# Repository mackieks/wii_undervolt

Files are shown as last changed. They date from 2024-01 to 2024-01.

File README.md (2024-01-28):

Adjustable regulator board for Wii undervolting testing and current measurement. Solderpad Hardware License v2.1 
 


- 3.5 - 5.5V input
- x4 MUN3CAD03-SE 0.6-3.3V 3A buck regulators
- Trimpots for output voltage adjustment (feedback resistors pre-tuned for Wii undervolting)
- 4-terminal current sense resistors for input and outputs
- [Mouser project with BOM
](https://www.mouser.com/ProjectManager/ProjectDetail.aspx?AccessID=8f9d8d9514)
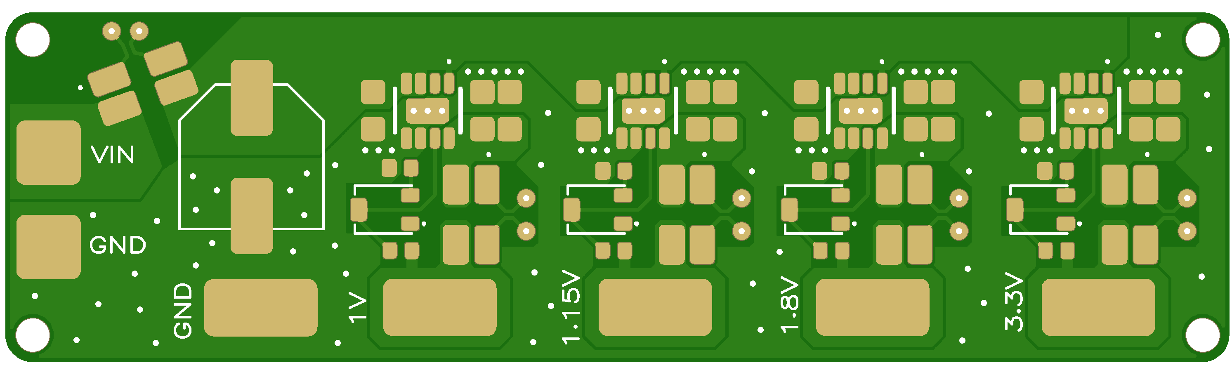
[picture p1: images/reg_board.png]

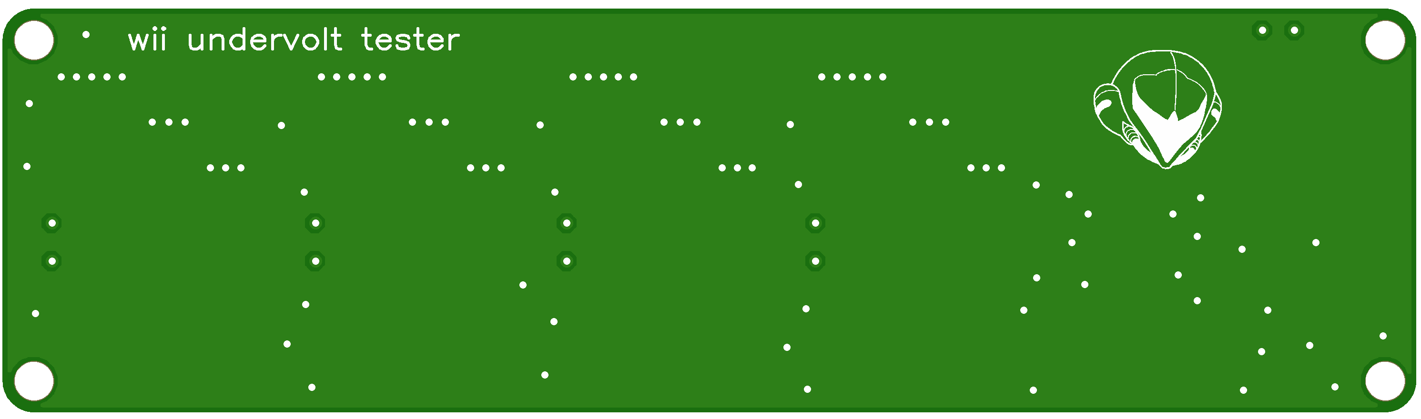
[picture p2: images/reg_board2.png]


Vin and each regulator output have dedicated 100-milliohm 4-terminal sense resistors. When powering a load from the reg board, you can measure across the resistors by poking your multimeter probes into the plated test pads. Multiply the voltage by 10 to get the load current in amps.

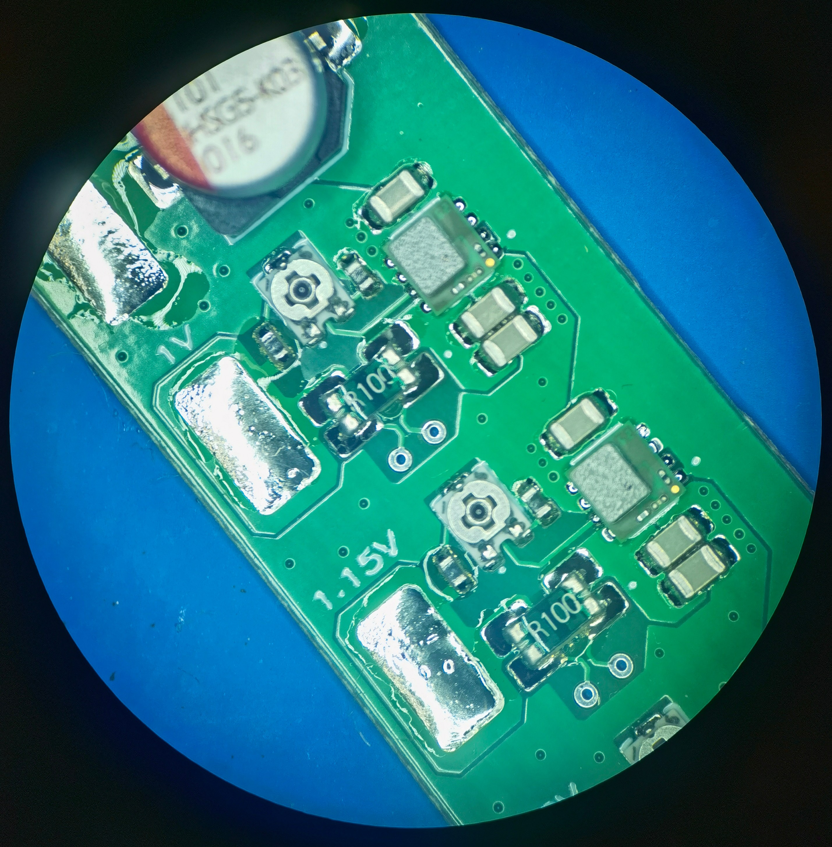
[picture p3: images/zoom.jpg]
 

Each regulator has a trimpot for adjusting the voltage. Turn it clockwise to increase Vout, and counterclockwise to decrease Vout. You can turn the pots with tweezers or a tiny, blunt Phillips screwdriver. The Vout ranges are bounded by resistors so that the entire pot range is usable (and to avoid pumping 5v into any of the rails.)

**Note:** the trimpots are fragile mechanical devices. If you turn them too far in one direction, they'll 'wrap around' to the other side. When overturned like this, there's a small region that won't produce a reasonable resistance, causing Vout to collapse. Just keep turning and Vout will jump back to the intended range.



## Schematic
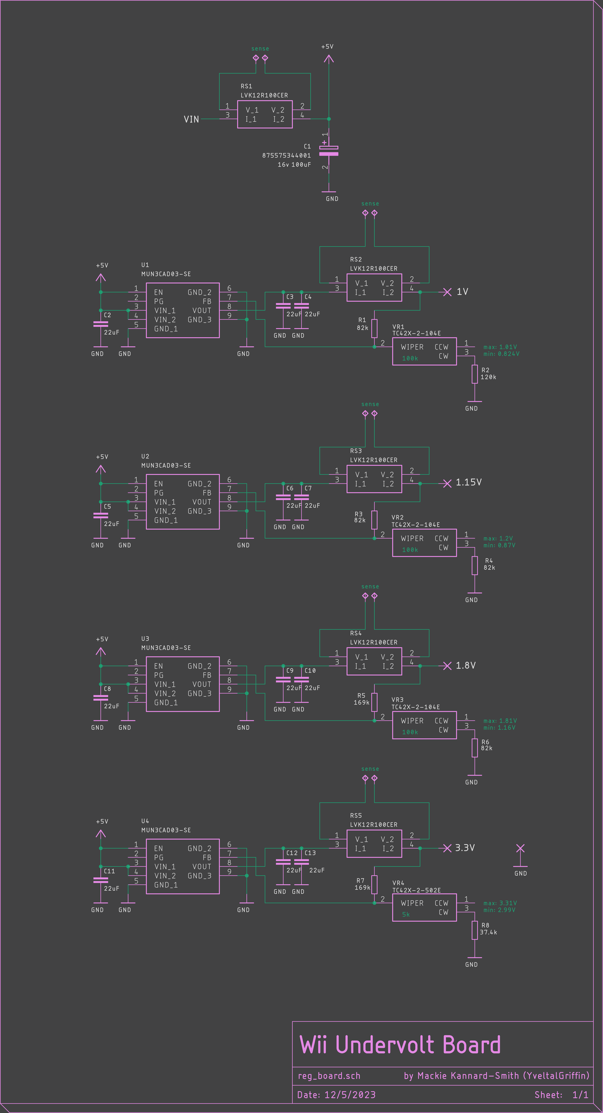
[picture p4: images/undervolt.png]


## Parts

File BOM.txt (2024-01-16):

Partlist

Exported from reg_board.sch at 1/16/2024 12:08 PM

EAGLE Version 9.6.2 Copyright (c) 1988-2020 Autodesk, Inc.

Assembly variant: 

Part     Value          Device       Package       Library        Sheet

C1       875575344001   875575344001 CAPAE660X610N SamacSys_Parts 1
C2       22uF           C-USC0603    C0603         resistor       1
C3       22uF           C-USC0603    C0603         resistor       1
C4       22uF           C-USC0603    C0603         resistor       1
C5       22uF           C-USC0603    C0603         resistor       1
C6       22uF           C-USC0603    C0603         resistor       1
C7       22uF           C-USC0603    C0603         resistor       1
C8       22uF           C-USC0603    C0603         resistor       1
C9       22uF           C-USC0603    C0603         resistor       1
C10      22uF           C-USC0603    C0603         resistor       1
C11      22uF           C-USC0603    C0603         resistor       1
C12      22uF           C-USC0603    C0603         resistor       1
C13      22uF           C-USC0603    C0603         resistor       1
R1       82k            R-US_R0402   R0402         resistor       1
R2       120k           R-US_R0402   R0402         resistor       1
R3       82k            R-US_R0402   R0402         resistor       1
R4       82k            R-US_R0402   R0402         resistor       1
R5       169k           R-US_R0402   R0402         resistor       1
R6       82k            R-US_R0402   R0402         resistor       1
R7       169k           R-US_R0402   R0402         resistor       1
R8       37.4k          R-US_R0402   R0402         resistor       1
RS1      LVK12R100CER   LVK12R100CER LVK12R100CER  SamacSys_Parts 1
RS2      LVK12R100CER   LVK12R100CER LVK12R100CER  SamacSys_Parts 1
RS3      LVK12R100CER   LVK12R100CER LVK12R100CER  SamacSys_Parts 1
RS4      LVK12R100CER   LVK12R100CER LVK12R100CER  SamacSys_Parts 1
RS5      LVK12R100CER   LVK12R100CER LVK12R100CER  SamacSys_Parts 1
U1       MUN3CAD03-SE   MUN3CAD03-SE MUN3CAD03SE   SamacSys_Parts 1
U2       MUN3CAD03-SE   MUN3CAD03-SE MUN3CAD03SE   SamacSys_Parts 1
U3       MUN3CAD03-SE   MUN3CAD03-SE MUN3CAD03SE   SamacSys_Parts 1
U4       MUN3CAD03-SE   MUN3CAD03-SE MUN3CAD03SE   SamacSys_Parts 1
VR1      TC42X-2-104E   TC42X-2-104E TC42X2103E    SamacSys_Parts 1
VR2      TC42X-2-104E   TC42X-2-104E TC42X2103E    SamacSys_Parts 1
VR3      TC42X-2-104E   TC42X-2-104E TC42X2103E    SamacSys_Parts 1
VR4      TC42X-2-502E   TC42X-2-104E TC42X2103E    SamacSys_Parts 1

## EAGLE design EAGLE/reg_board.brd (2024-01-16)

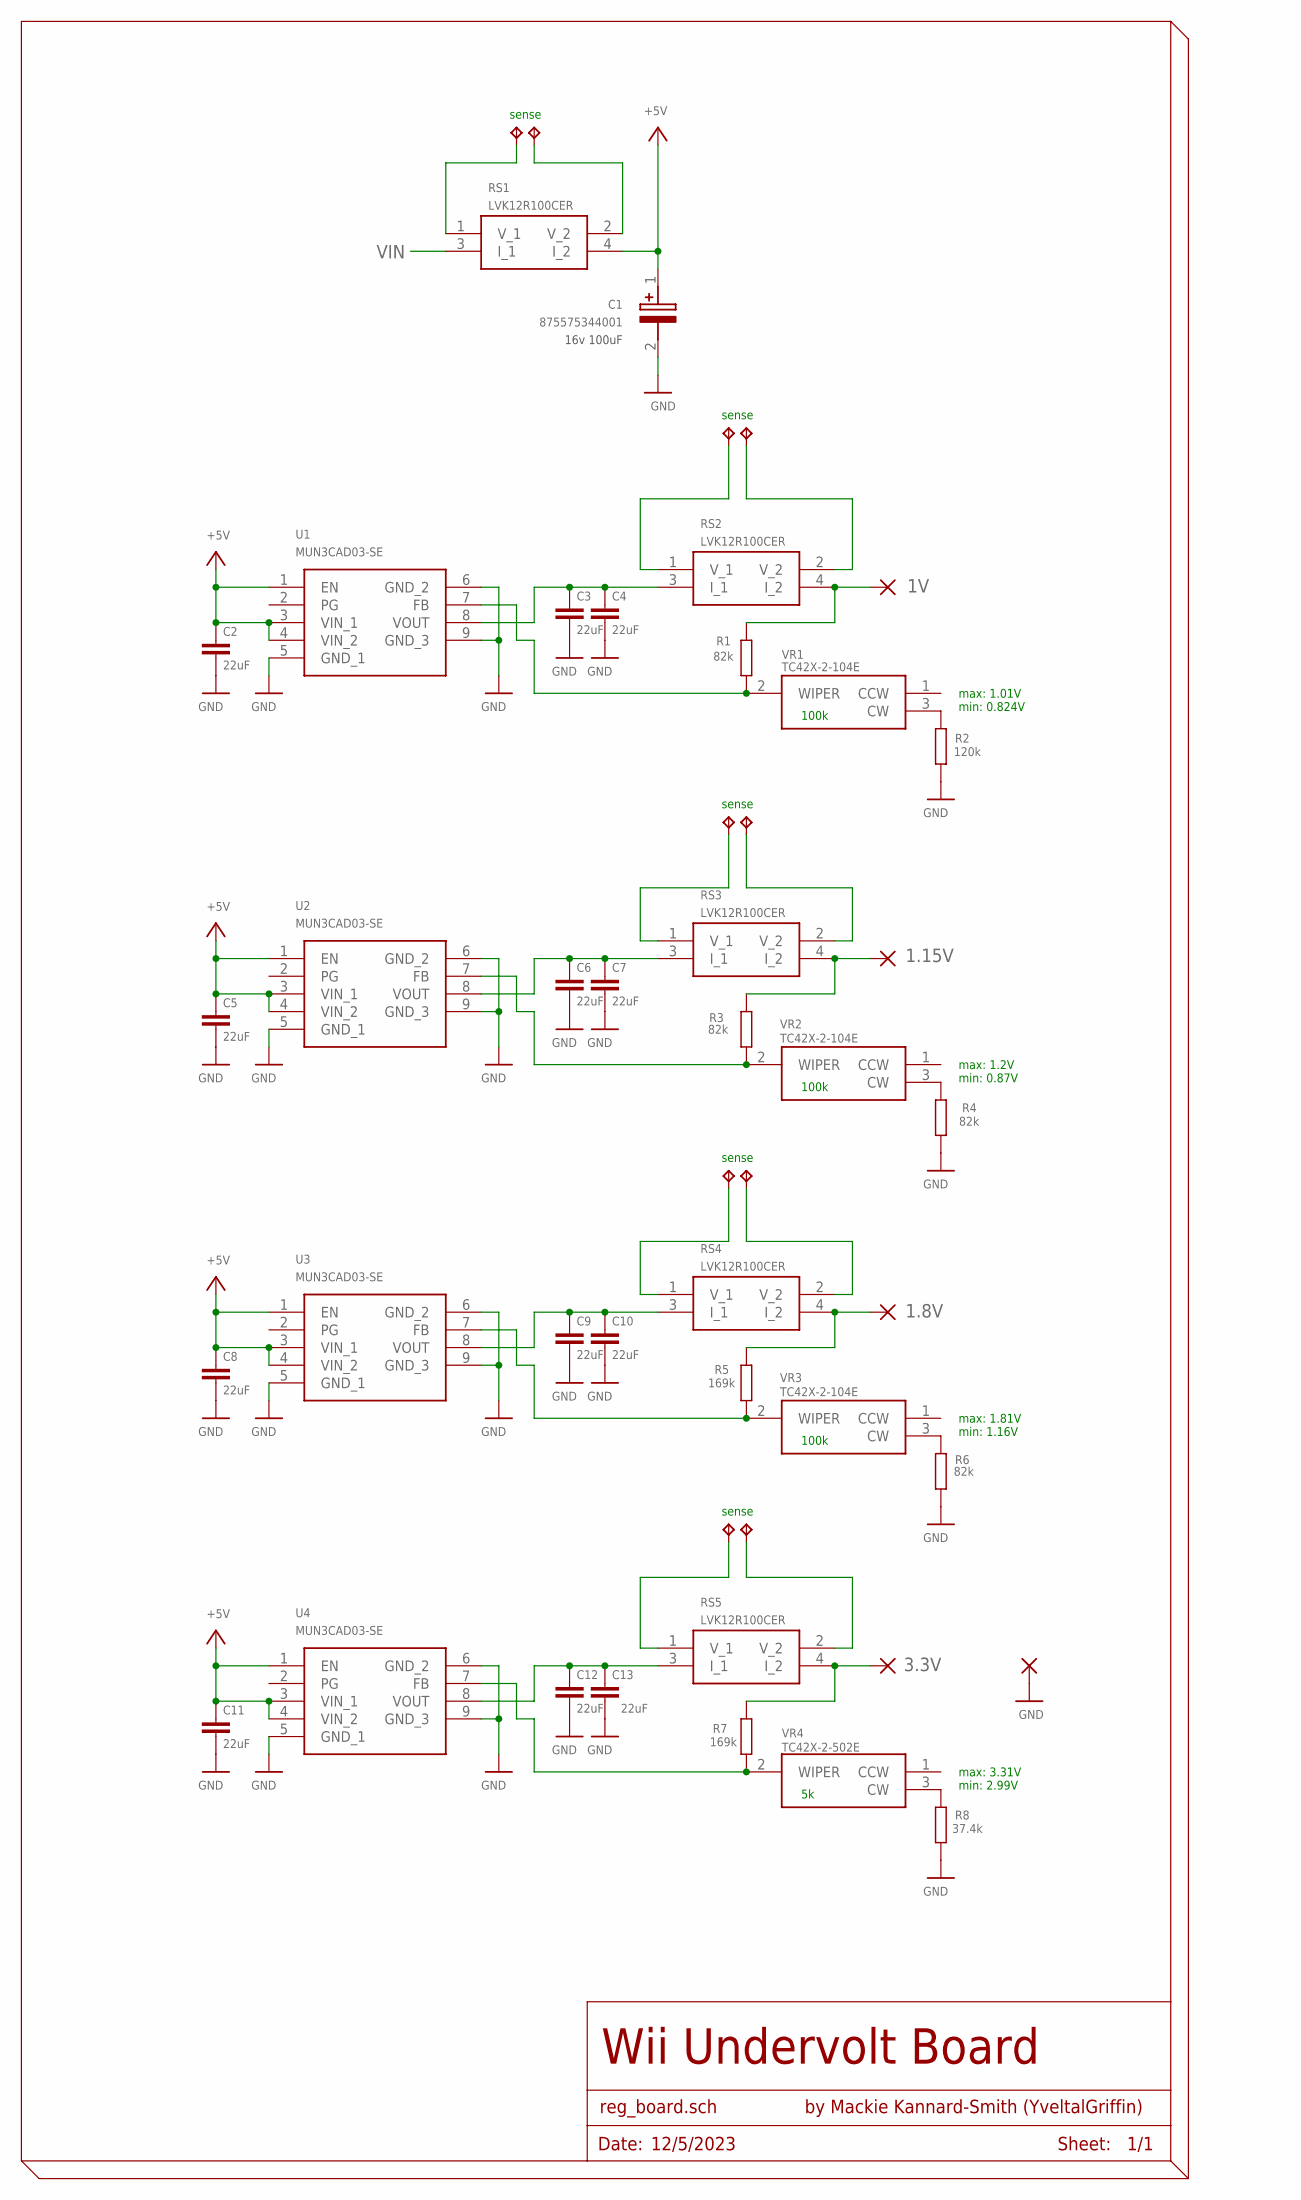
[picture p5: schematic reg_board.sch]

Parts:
C1: 875575344001; CAPAE660X610N
C2, C3, C4, C5, C6, C7, C8, C9, C10, C11, C12, C13: 22uF; C0603
PAD1, PAD2, PAD3, PAD4, PAD5: SMD5; SMD2,54-5,08
R1, R3, R4, R6: 82k; R0402
R2: 120k; R0402
R5, R7: 169k; R0402
R8: 37.4k; R0402
RS1, RS2, RS3, RS4, RS5: LVK12R100CER
TP1, TP2, TP3, TP4, TP5, TP6, TP7, TP8, TP9, TP10: TPTP08R; TP08R
U1, U2, U3, U4: MUN3CAD03-SE; MUN3CAD03SE
VR1, VR2, VR3: TC42X-2-104E; TC42X2103E
VR4: TC42X-2-502E; TC42X2103E

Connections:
1.8V: PAD4.1, R5.2, RS4.4 (I_2)
1.15V: PAD3.1, R3.2, RS3.4 (I_2)
1V: PAD1.1, R1.2, RS2.4 (I_2)
3.3V: PAD5.1, R7.2, RS5.4 (I_2)
+5V: C1.1 (+), C2.1, C5.1, C8.1, C11.1, RS1.4 (I_2), U1.1 (EN), U1.3 (VIN_1), U1.4 (VIN_2), U2.1 (EN), U2.3 (VIN_1), U2.4 (VIN_2), U3.1 (EN), U3.3 (VIN_1), U3.4 (VIN_2), U4.1 (EN), U4.3 (VIN_1), U4.4 (VIN_2)
GND: C1.2 (-), C2.2, C3.2, C4.2, C5.2, C6.2, C7.2, C8.2, C9.2, C10.2, C11.2, C12.2, C13.2, PAD2.1, R2.1, R4.1, R6.1, R8.1, U1.5 (GND_1), U1.6 (GND_2), U1.9 (GND_3), U2.5 (GND_1), U2.6 (GND_2), U2.9 (GND_3), U3.5 (GND_1), U3.6 (GND_2), U3.9 (GND_3), U4.5 (GND_1), U4.6 (GND_2), U4.9 (GND_3)
unnamed: R2.2, VR1.3 (CW)
unnamed: R4.2, VR2.3 (CW)
unnamed: R1.1, U1.7 (FB), VR1.2 (WIPER)
unnamed: RS2.1 (V_1), TP1.TP
unnamed: RS2.2 (V_2), TP2.TP
unnamed: R6.2, VR3.3 (CW)
unnamed: RS1.2 (V_2), TP3.TP
unnamed: RS1.1 (V_1), TP4.TP
unnamed: R3.1, U2.7 (FB), VR2.2 (WIPER)
unnamed: RS3.1 (V_1), TP5.TP
unnamed: RS3.2 (V_2), TP6.TP
unnamed: R5.1, U3.7 (FB), VR3.2 (WIPER)
unnamed: RS4.1 (V_1), TP7.TP
unnamed: RS4.2 (V_2), TP8.TP
unnamed: R7.1, U4.7 (FB), VR4.2 (WIPER)
unnamed: RS5.1 (V_1), TP9.TP
unnamed: RS5.2 (V_2), TP10.TP
unnamed: R8.2, VR4.3 (CW)
VIN: RS1.3 (I_1)
VOUT1: C3.1, C4.1, RS2.3 (I_1), U1.8 (VOUT)
VOUT2: C6.1, C7.1, RS3.3 (I_1), U2.8 (VOUT)
VOUT3: C9.1, C10.1, RS4.3 (I_1), U3.8 (VOUT)
VOUT4: C12.1, C13.1, RS5.3 (I_1), U4.8 (VOUT)

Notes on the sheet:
100k
max: 1.01V min: 0.824V
max: 1.2V min: 0.87V
max: 1.81V min: 1.16V
max: 3.31V min: 2.99V
16v 100uF
sense
Wii Undervolt Board
reg_board.sch
by Mackie Kannard-Smith (YveltalGriffin)
Date:
12/5/2023
Sheet: 1/1

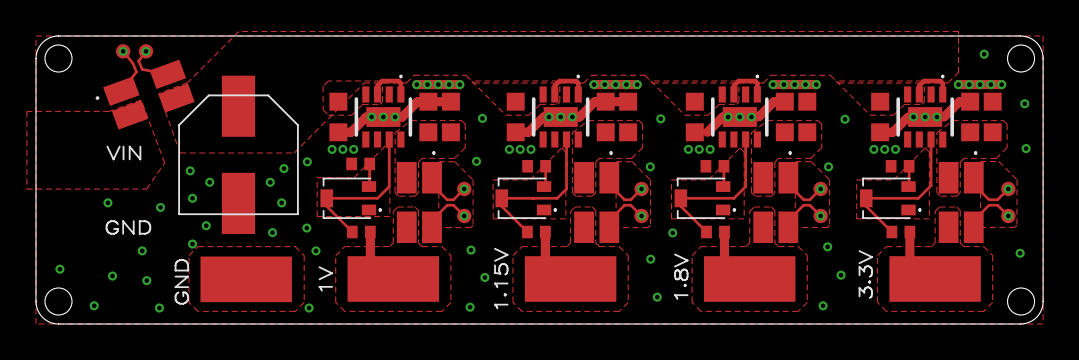
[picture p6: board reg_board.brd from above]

Board: 2 copper layers, 56.0 x 16.0 mm, 49 parts (0 on the bottom side), 28 nets.
